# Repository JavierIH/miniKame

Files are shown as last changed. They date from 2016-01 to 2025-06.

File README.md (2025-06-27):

> 📌 **A newer and more advanced version of this robot is available:** [Kame32](https://github.com/javierih/kame32)

# Kame (MiniKame)

<p align="center">
 
</p>

[What components do I need for building this robot?](https://github.com/bqlabs/miniKame/wiki/BOM)

[Where can I find the assembly model?](https://github.com/bqlabs/miniKame/blob/develop/parts/freecad/miniKame.fcstd)

[How are servos connected to the NodeMCU V2 board?](https://github.com/JavierIH/miniKame/wiki/Map-between-servos-and-board-pins)

# License

Son of [Kame](https://github.com/bqlabs/kame)

<p align="center">

</p>

# Remixes
[PoorKame](https://github.com/owenlab/PoorKame) by [owenlab](https://github.com/owenlab)

[FatKame](https://github.com/Blomdoft/fatKame) by [Blomdoft](https://github.com/Blomdoft)

# Other

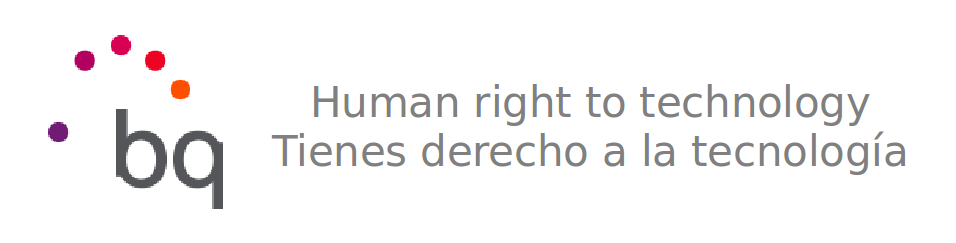
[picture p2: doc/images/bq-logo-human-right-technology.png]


Sponsored by BQ till march 2016

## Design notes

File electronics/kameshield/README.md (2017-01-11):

<p align="center">

</p>

# Attention:

This PCB is just a proof of concept of a shield for putting together the needed connectors for servos and battery on a NodeMCU V2. At this time, it has been fabricated an only one board (the one is actually being mounted on PoorKame) with a hobby-level milling machine, so I can't guarantee it to work or even if it is safe for being used with another specific hardware.

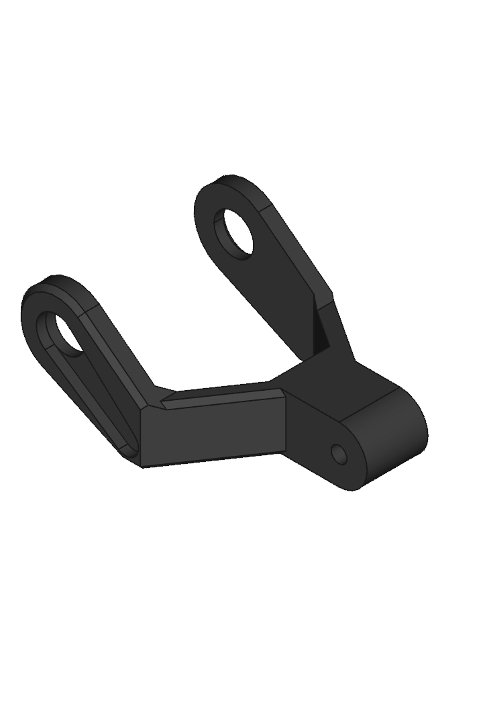
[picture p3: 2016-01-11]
doc/images/leftLegB.png

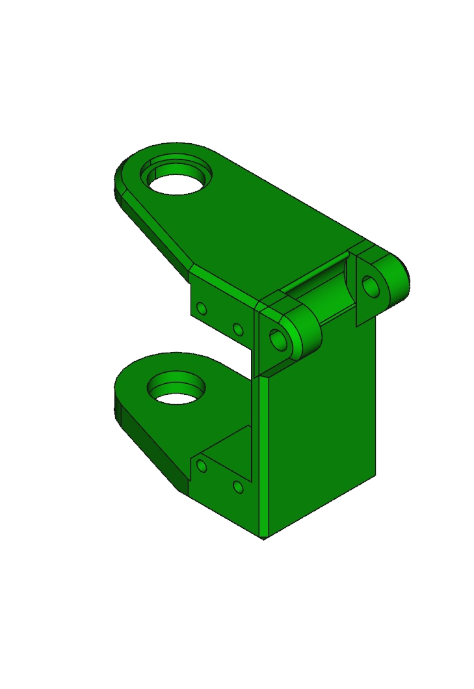
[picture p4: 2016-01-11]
doc/images/leftBracket.png

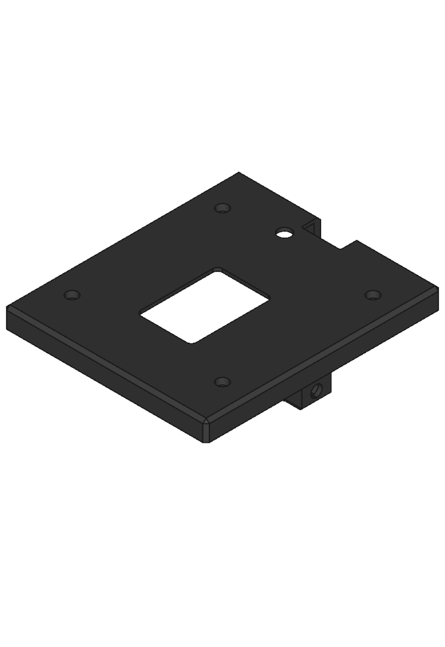
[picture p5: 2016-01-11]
doc/images/bodyA.png

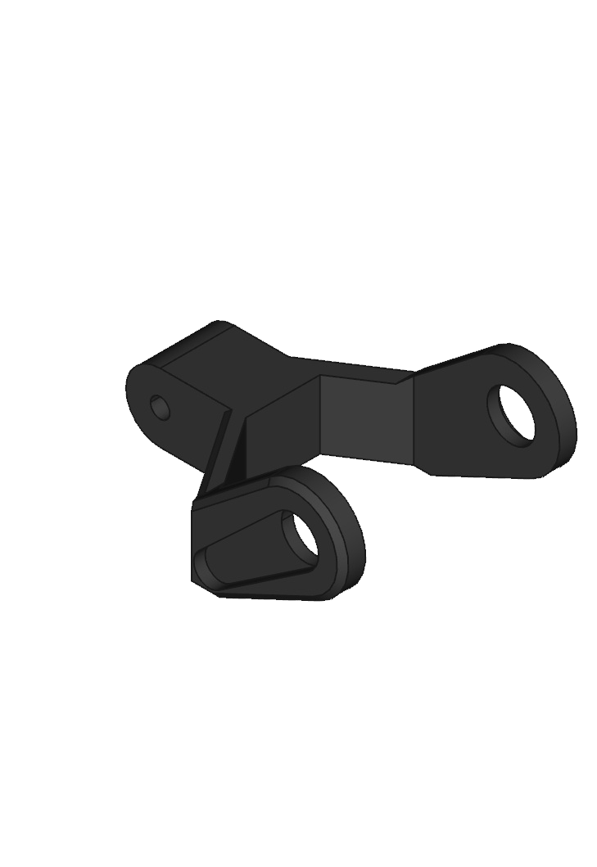
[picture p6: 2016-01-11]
doc/images/rightLegB.png

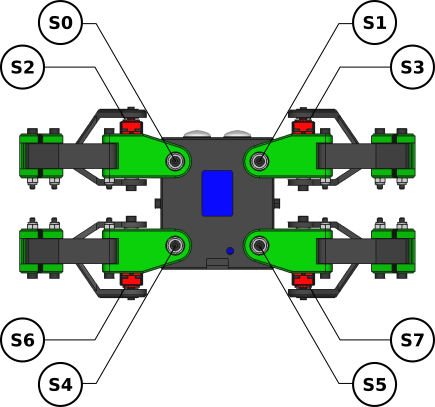
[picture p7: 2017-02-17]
doc/images/servo_scheme.png

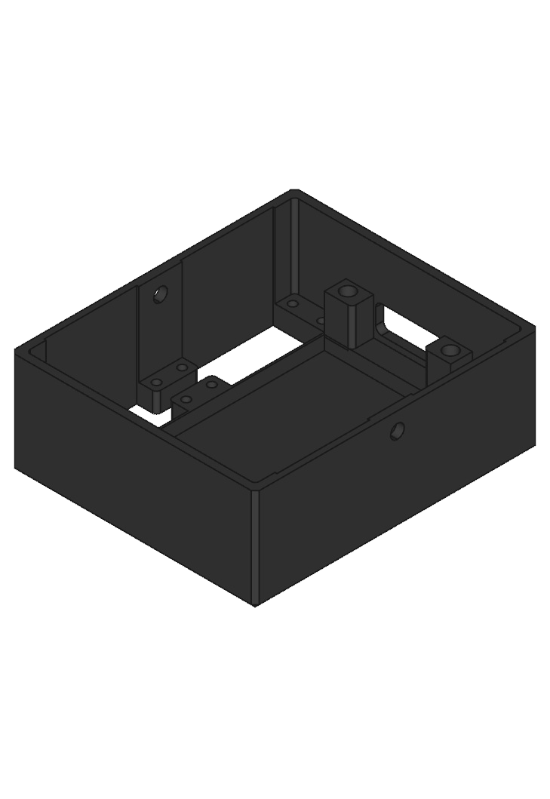
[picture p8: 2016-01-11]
doc/images/bodyB.png

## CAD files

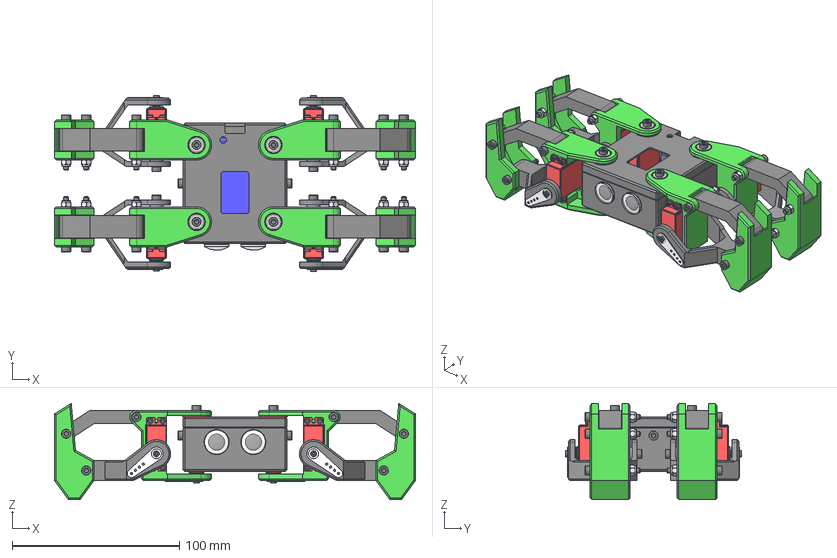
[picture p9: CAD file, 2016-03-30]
parts/freecad/miniKame.fcstd
216.0 x 105.3 x 57.6 mm
Clone of TGY-306G003
Clone of TGY-306G
Clone of TGY-306G004
Clone of TGY-306G005
Clone of TGY-306G006
Clone of TGY-306G007
Clone of TGY-306G008
Clone of TGY-306G009
Clone of horn001 (Mirror #9)
Clone of horn002 (Mirror #10)
Clone of horn001 (Mirror #11)
Clone of horn002 (Mirror #12)
Clone of legA (Mirror #17)
Clone of foot (Mirror #18)
Clone of bracket (Mirror #20)
Clone of legA (Mirror #21)
Clone of foot (Mirror #22)
Clone of bracket (Mirror #24)
Clone of legB (Mirror #30)
Clone of legB (Mirror #31)
Clone of spacer (Mirror #39)
Clone of spacer (Mirror #40)
Clone of bodyB
Clone of bodyA
eye-base
black-eye
eye-cover
eye-base001
eye-cover001
black-eye001
Clone of bearing
Clone of bearing002
Clone of bearing003
Clone of bearing004
Clone of bearing001
Clone of bearing005
Clone of bearing006
Clone of bearing007
Clone of hex-m3-8mm
Clone of hex-m3-8mm001
Clone of hex-m3-8mm002
Clone of hex-m3-8mm003
Clone of hex-m3-8mm004
Clone of hex-m3-8mm005
Clone of hex-m3-8mm006
Clone of hex-m3-8mm007
Clone of hex-m3-8mm008
Clone of hex-m3-8mm009
Clone of hex-m3-30mm
Clone of hex-m3-30mm001
Clone of hex-m3-30mm002
Clone of hex-m3-30mm003
Clone of hex-m3-30mm004
Clone of hex-m3-30mm005
Clone of hex-m3-30mm006
Clone of hex-m3-30mm007
Clone of hex-m3-30mm008
Clone of hex-m3-30mm009
Clone of hex-m3-30mm010
Clone of hex-m3-30mm011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

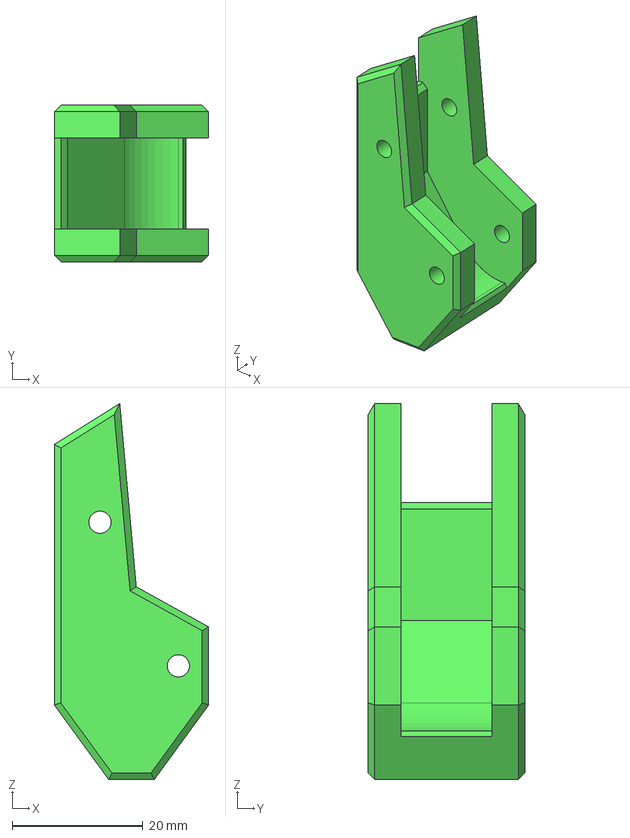
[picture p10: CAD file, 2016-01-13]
parts/step/foot.step
23.6 x 24.0 x 57.6 mm

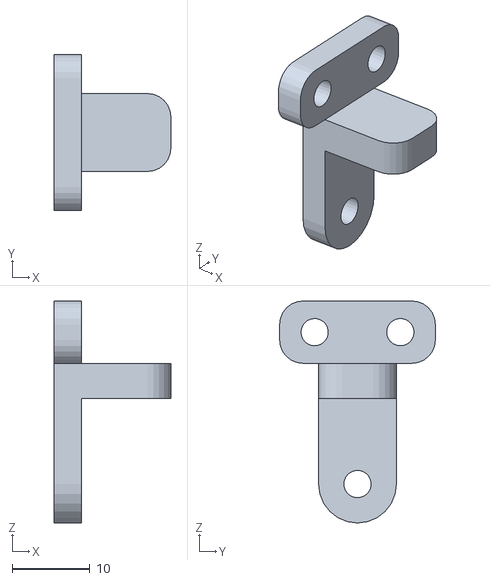
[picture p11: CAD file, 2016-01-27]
parts/stl/support.stl
15.0 x 20.0 x 28.5

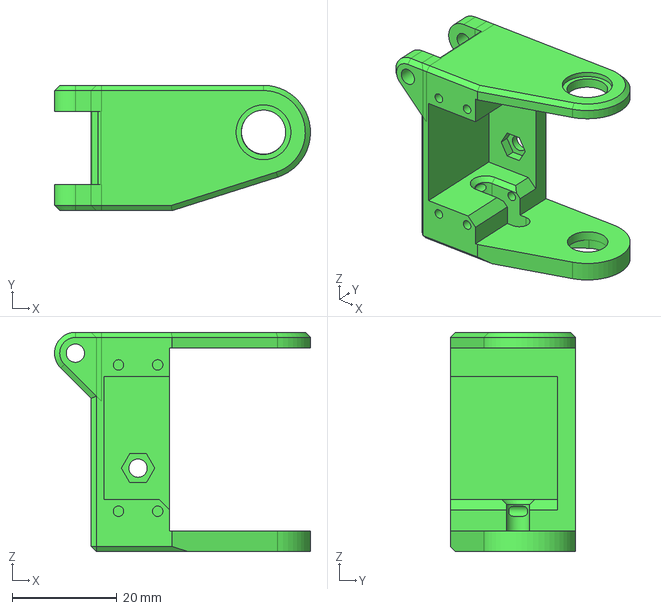
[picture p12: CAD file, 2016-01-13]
parts/step/rightBracket.step
49.0 x 24.0 x 42.0 mm

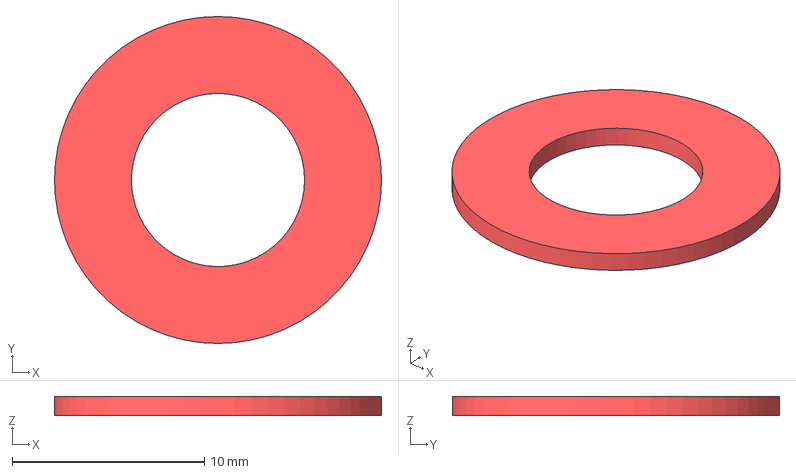
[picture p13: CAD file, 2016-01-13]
parts/step/spacer.step
17.0 x 17.0 x 1.00 mm

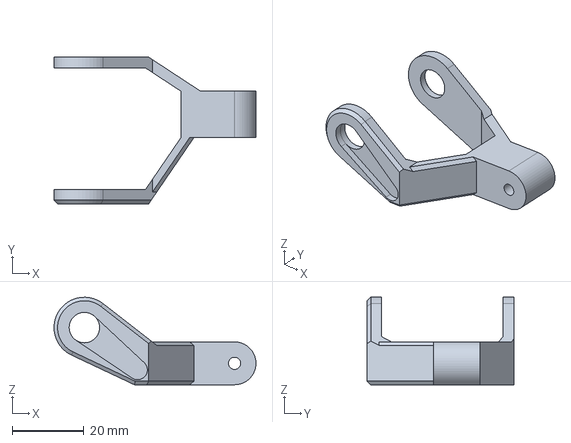
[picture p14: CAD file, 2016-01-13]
parts/step/leftLegB.step
56.5 x 41.0 x 24.5 mm

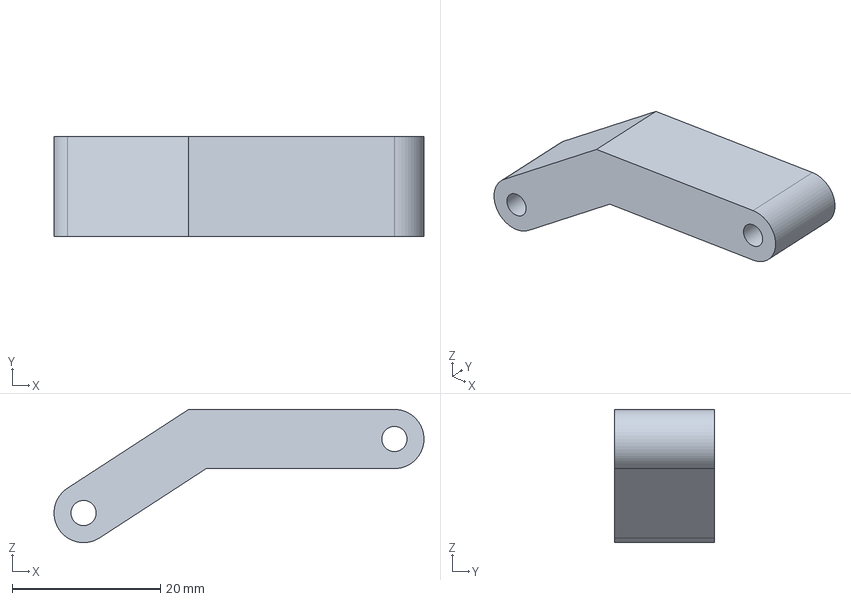
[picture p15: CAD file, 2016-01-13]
parts/step/legA.step
50.0 x 13.5 x 18.0 mm

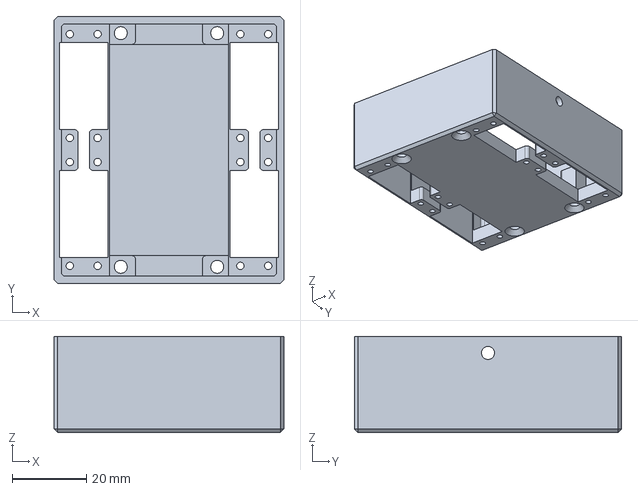
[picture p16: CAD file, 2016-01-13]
parts/step/bodyB.step
62.0 x 72.0 x 26.0 mm

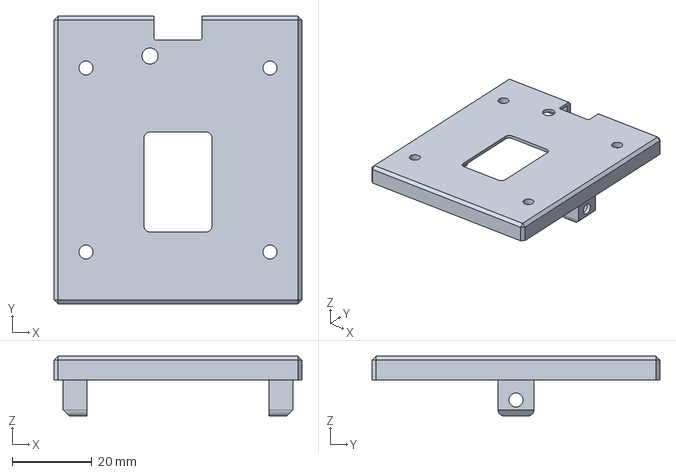
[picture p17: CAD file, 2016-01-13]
parts/step/bodyA.step
62.0 x 72.0 x 15.0 mm

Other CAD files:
parts/step/leftBracket.step
parts/step/rightLegB.step
parts/stl/bodyA.stl
parts/stl/bodyB.stl
parts/stl/foot.stl
parts/stl/leftBracket.stl
parts/stl/leftLegB.stl
parts/stl/legA.stl
parts/stl/rightBracket.stl
parts/stl/rightLegB.stl
parts/stl/spacer.stl

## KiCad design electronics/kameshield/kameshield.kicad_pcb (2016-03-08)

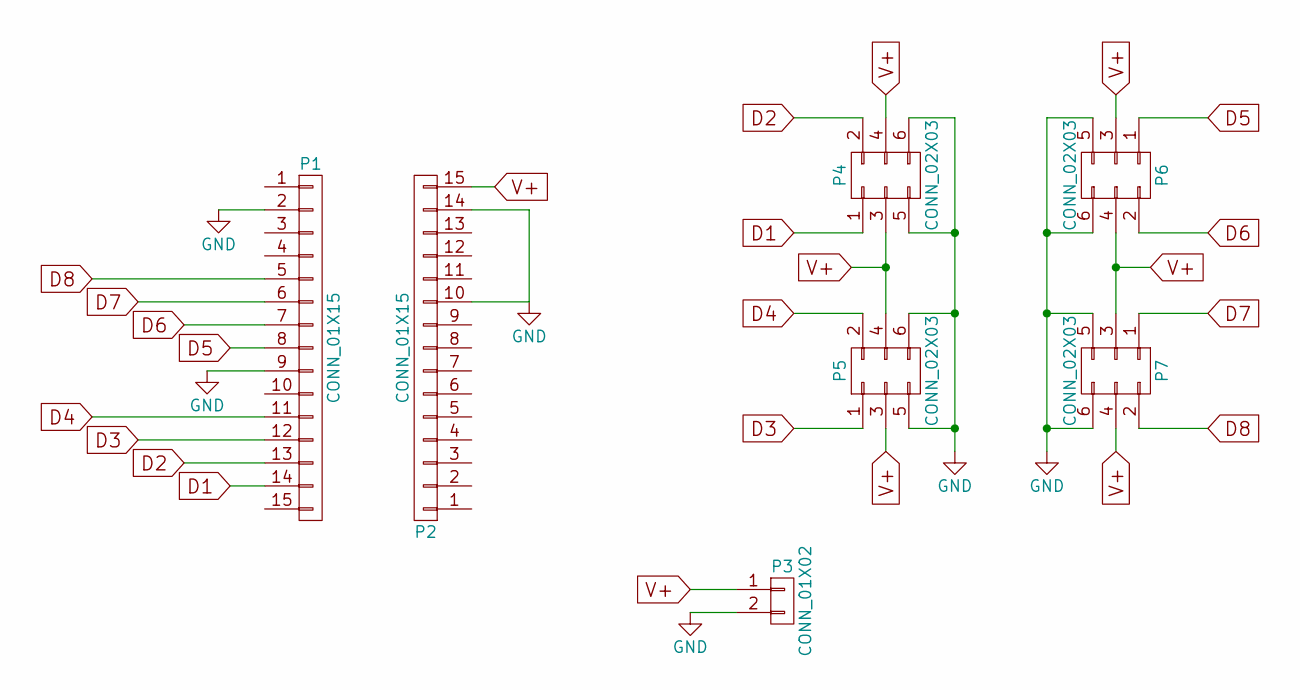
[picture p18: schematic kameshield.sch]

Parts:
P1, P2: CONN_01X15; Pin_Header_Straight_1x15
P3: CONN_01X02; Pin_Header_Straight_1x02
P4, P5, P6, P7: CONN_02X03; Pin_Header_Angled_2x03

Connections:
D1: P1.14, P4.1
D2: P1.13, P4.2
D3: P1.12, P5.1
D4: P1.11, P5.2
D5: P1.8, P6.1
D6: P1.7, P6.2
D7: P1.6, P7.1
D8: P1.5, P7.2
GND: P1.2, P1.9, P2.10, P2.14, P3.2, P4.5, P4.6, P5.5, P5.6, P6.5, P6.6, P7.5, P7.6
V+: P2.15, P3.1, P4.3, P4.4, P5.3, P5.4, P6.3, P6.4, P7.3, P7.4

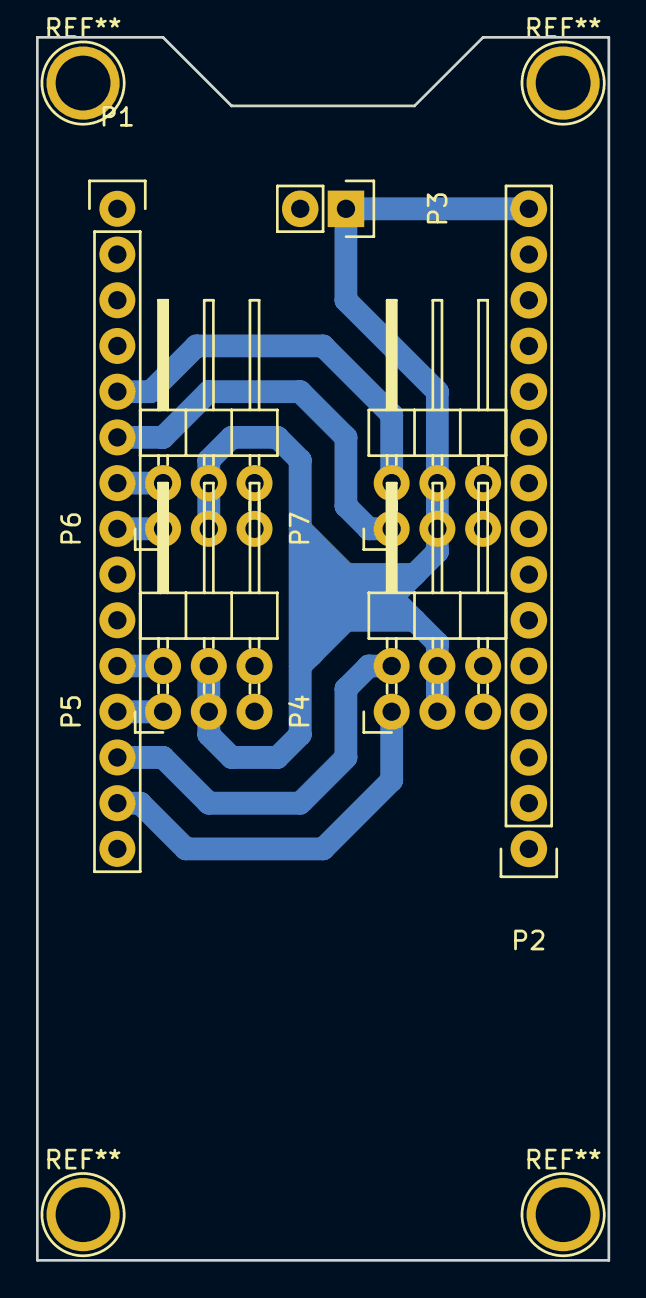
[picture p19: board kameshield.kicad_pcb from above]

Board: 2 copper layers, 31.8 x 67.9 mm, 7 parts (0 on the bottom side), 10 nets.

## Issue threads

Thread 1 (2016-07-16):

no ipaddress displayed on terminal

drepou, 2016-07-16:
Hi JavierIH

I try your sample code on my nodeMCU amica V2 i noticed that ipAddress of the board is not correctly written by  "Serial.println(WiFi.localIP());" in main.cpp

checked on arduino sample code this look to work much better :

        IPAddress myIP = WiFi.softAPIP();
        Serial.print("AP IP address: ");
	Serial.println(myIP);

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

Best Regards Yohan

JavierIH, 2016-07-18:
Hi drepou

You are right, I have just checked the code and it wasn't working properly. I'm going to update it with your code, which seems to work fine.

Thank you very much for your feedback!!!!!

drepou, 2016-07-25:
My plaisure to share and contribute...
Still Wait for my bearing to mount my kame

See you
Yohan

Envoyé de mon iPhone

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

Closed 2016-07-18.

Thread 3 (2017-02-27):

BodyB.stl file is wrong

ThorsAvenger, 2017-02-27:
The stl file for the part bodyB is wrong. Perhaps it got mixed up with another model?
https://github.com/JavierIH/miniKame/blob/develop/parts/stl/bodyB.stl

JavierIH, 2017-02-27:
Hi @ThorsAvenger , you are right this file is part of another robot, I have no idea what it is doing here...
Thank you very much for your feedback!

Closed 2017-02-27.

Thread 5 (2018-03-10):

Control it?

isoriaa, 2018-03-10:
I need some help, how to control from mobile phone, i conect to kame wifi go to 192.168.4.1 and I don`t know what to do. Is it a web, do I need a tcp socket?. Is there any android app to do it?

VTHokiEE, 2018-03-12:
I used a few tutorials that I found on-line to create a web server for the ESP8266 which hosted a page of buttons that I could press to control the robot. When the buttons are pressed they post a URL that the web server parses to obtain the command for the robot.

wheatgrinder, 2019-05-29:
you can get a telnet client for your phone.  Connect wifi to AP, connect the telnet app to the server and port.  Once connected via telnet terminal, you can send number keys to do the actions in the code.

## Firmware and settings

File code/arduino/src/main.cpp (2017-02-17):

#include <Arduino.h>
#include <ESP8266WiFi.h>
#include <WiFiClient.h>
#include <Servo.h>
#include "minikame.h"



// Wifi Access Point configuration
const char* ssid = "kame";
const char* password = "asdf";

void parseData(String data);

MiniKame robot;
WiFiServer server(80);
bool running=0;
String input;


void setup() {
    WiFi.mode(WIFI_AP);
    WiFi.softAP(ssid, password);
    server.begin();
    Serial.begin(115200);

    delay(1000);
    robot.init();
}

void loop() {
    WiFiClient client = server.available();
    if (!client) {
        IPAddress myIP = WiFi.softAPIP();
        Serial.print("AP IP address: ");
        Serial.println(myIP);
        delay(1000);
    }
    while (client.connected()) {
        if (running){
            Serial.println("running");
            if (client.available()) {
                while(client.available()) input = client.readStringUntil('+');
                parseData(input);
            }
            else {
                Serial.println("Keep Moving");
                parseData(input);
            }
        }
        else{
            Serial.println("Normal mode");
            if (client.available()) {
                while(client.available()) input = client.readStringUntil('+');
                parseData(input);
            }
            else robot.home();
        }
    }
}

void parseData(String data){

    switch (data.toInt()){

        case 1: // Up
            robot.walk(1,550);
            running = 1;
            break;

        case 2: // Down
            break;

        case 3: // Left
            robot.turnL(1,550);
            running = 1;
            break;

        case 4: // Right
            robot.turnR(1,550);
            running = 1;
            break;

        case 5: // STOP
            running = 0;
            break;

        case 6: // heart
            robot.pushUp(2,2000);
            break;

        case 7: // fire
            robot.upDown(4,250);
            break;

        case 8: // skull
            robot.jump();
            break;

        case 9: // cross
            robot.hello();
            break;

        case 10: // punch
            robot.frontBack(4,200);
            break;

        case 11: // mask
            robot.dance(2,1000);
            break;

        default:
            robot.home();
            break;
    }
}

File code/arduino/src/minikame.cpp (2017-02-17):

#include "minikame.h"


void MiniKame::init(){
    // Map between servos and board pins
    board_pins[0] = D1; // Servo S0
    board_pins[1] = D4; // Servo S1
    board_pins[2] = D8; // Servo S2
    board_pins[3] = D6; // Servo S3
    board_pins[4] = D7; // Servo S4
    board_pins[5] = D5; // Servo S5
    board_pins[6] = D2; // Servo S6
    board_pins[7] = D3; // Servo S7

    // Trim values for zero position calibration.
    trim[0] = 0;
    trim[1] = -8;
    trim[2] = 8;
    trim[3] = 5;
    trim[4] = 2;
    trim[5] = -6;
    trim[6] = 6;
    trim[7] = 5;

    // Set reverse movement
    for (int i=0; i<8; i++) reverse[i] = false;

    // Init an oscillator for each servo
    for(int i=0; i<8; i++){
        oscillator[i].start();
        servo[i].attach(board_pins[i]);
    }
    zero();
}

void MiniKame::turnR(float steps, int T=600){
    int x_amp = 15;
    int z_amp = 15;
    int ap = 15;
    int hi = 23;
    int period[] = {T, T, T, T, T, T, T, T};
    int amplitude[] = {x_amp,x_amp,z_amp,z_amp,x_amp,x_amp,z_amp,z_amp};
    int offset[] = {90+ap,90-ap,90-hi,90+hi,90-ap,90+ap,90+hi,90-hi};
    int phase[] = {0,180,90,90,180,0,90,90};

    execute(steps, period, amplitude, offset, phase);
}

void MiniKame::turnL(float steps, int T=600){
    int x_amp = 15;
    int z_amp = 15;
    int ap = 15;
    int hi = 23;
    int period[] = {T, T, T, T, T, T, T, T};
    int amplitude[] = {x_amp,x_amp,z_amp,z_amp,x_amp,x_amp,z_amp,z_amp};
    int offset[] = {90+ap,90-ap,90-hi,90+hi,90-ap,90+ap,90+hi,90-hi};
    int phase[] = {180,0,90,90,0,180,90,90};

    execute(steps, period, amplitude, offset, phase);
}

void MiniKame::dance(float steps, int T=600){
    int x_amp = 0;
    int z_amp = 40;
    int ap = 30;
    int hi = 20;
    int period[] = {T, T, T, T, T, T, T, T};
    int amplitude[] = {x_amp,x_amp,z_amp,z_amp,x_amp,x_amp,z_amp,z_amp};
    int offset[] = {90+ap,90-ap,90-hi,90+hi,90-ap,90+ap,90+hi,90-hi};
    int phase[] = {0,0,0,270,0,0,90,180};

    execute(steps, period, amplitude, offset, phase);
}

void MiniKame::frontBack(float steps, int T=600){
    int x_amp = 30;
    int z_amp = 25;
    int ap = 20;
    int hi = 30;
    int period[] = {T, T, T, T, T, T, T, T};
    int amplitude[] = {x_amp,x_amp,z_amp,z_amp,x_amp,x_amp,z_amp,z_amp};
    int offset[] = {90+ap,90-ap,90-hi,90+hi,90-ap,90+ap,90+hi,90-hi};
    int phase[] = {0,180,270,90,0,180,90,270};

    execute(steps, period, amplitude, offset, phase);
}

void MiniKame::run(float steps, int T=5000){
    int x_amp = 15;
    int z_amp = 15;
    int ap = 15;
    int hi = 15;
    int front_x = 6;
    int period[] = {T, T, T, T, T, T, T, T};
    int amplitude[] = {x_amp,x_amp,z_amp,z_amp,x_amp,x_amp,z_amp,z_amp};
    int offset[] = {    90+ap-front_x,
                        90-ap+front_x,
                        90-hi,
                        90+hi,
                        90-ap-front_x,
                        90+ap+front_x,
                        90+hi,
                        90-hi
                    };
    int phase[] = {0,0,90,90,180,180,90,90};

    execute(steps, period, amplitude, offset, phase);
}

void MiniKame::omniWalk(float steps, int T, bool side, float turn_factor){
    int x_amp = 15;
    int z_amp = 15;
    int ap = 15;
    int hi = 23;
    int front_x = 6 * (1-pow(turn_factor, 2));
    int period[] = {T, T, T, T, T, T, T, T};
    int amplitude[] = {x_amp,x_amp,z_amp,z_amp,x_amp,x_amp,z_amp,z_amp};
    int offset[] = {    90+ap-front_x,
                        90-ap+front_x,
                        90-hi,
                        90+hi,
                        90-ap-front_x,
                        90+ap+front_x,
                        90+hi,
                        90-hi
                    };

    int phase[8];
    if (side){
        int phase1[] =  {0,   0,   90,  90,  180, 180, 90,  90};
        int phase2R[] = {0,   180, 90,  90,  180, 0,   90,  90};
        for (int i=0; i<8; i++)
            phase[i] = phase1[i]*(1-turn_factor) + phase2R[i]*turn_factor;
    }
    else{
        int phase1[] =  {0,   0,   90,  90,  180, 180, 90,  90};
        int phase2L[] = {180, 0,   90,  90,  0,   180, 90,  90};
        for (int i=0; i<8; i++)
            phase[i] = phase1[i]*(1-turn_factor) + phase2L[i]*turn_factor + oscillator[i].getPhaseProgress();
    }

    execute(steps, period, amplitude, offset, phase);
}

void MiniKame::moonwalkL(float steps, int T=5000){
    int z_amp = 45;
    int period[] = {T, T, T, T, T, T, T, T};
    int amplitude[] = {0,0,z_amp,z_amp,0,0,z_amp,z_amp};
    int offset[] = {90, 90, 90, 90, 90, 90, 90, 90};
    int phase[] = {0,0,0,120,0,0,180,290};

    execute(steps, period, amplitude, offset, phase);
}

void MiniKame::walk(float steps, int T=5000){
    int x_amp = 15;
    int z_amp = 20;
    int ap = 20;
    int hi = 10;
    int front_x = 12;
    int period[] = {T, T, T/2, T/2, T, T, T/2, T/2};
    int amplitude[] = {x_amp,x_amp,z_amp,z_amp,x_amp,x_amp,z_amp,z_amp};
    int offset[] = {   90+ap-front_x,
                                90-ap+front_x,
                                90-hi,
                                90+hi,
                                90-ap-front_x,
                                90+ap+front_x,
                                90+hi,
                                90-hi
                    };
    int  phase[] = {90, 90, 270, 90, 270, 270, 90, 270};

    for (int i=0; i<8; i++){
        oscillator[i].reset();
        oscillator[i].setPeriod(period[i]);
        oscillator[i].setAmplitude(amplitude[i]);
        oscillator[i].setPhase(phase[i]);
        oscillator[i].setOffset(offset[i]);
    }

    _final_time = millis() + period[0]*steps;
    _init_time = millis();
    bool side;
    while (millis() < _final_time){
        side = (int)((millis()-_init_time) / (period[0]/2)) % 2;
        setServo(0, oscillator[0].refresh());
        setServo(1, oscillator[1].refresh());
        setServo(4, oscillator[4].refresh());
        setServo(5, oscillator[5].refresh());

        if (side == 0){
            setServo(3, oscillator[3].refresh());
            setServo(6, oscillator[6].refresh());
        }
        else{
            setServo(2, oscillator[2].refresh());
            setServo(7, oscillator[7].refresh());
        }
        delay(1);
    }
}

void MiniKame::upDown(float steps, int T=5000){
    int x_amp = 0;
    int z_amp = 35;
    int ap = 20;
    int hi = 25;
    int front_x = 0;
    int period[] = {T, T, T, T, T, T, T, T};
    int amplitude[] = {x_amp,x_amp,z_amp,z_amp,x_amp,x_amp,z_amp,z_amp};
    int offset[] = {    90+ap-front_x,
                        90-ap+front_x,
                        90-hi,
                        90+hi,
                        90-ap-front_x,
                        90+ap+front_x,
                        90+hi,
                        90-hi
                    };
    int phase[] = {0,0,90,270,180,180,270,90};

    execute(steps, period, amplitude, offset, phase);
}
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

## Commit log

2015-11-26 Add freecad project
    [miniKame.fcstd]
2015-11-26 Add stl files
    [bodyA.stl, bodyB.stl, bracket.stl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]
2015-11-30 updated body for nodemcu
    [bodyA.stl, bodyB.stl, miniKame.fcstd]
2015-12-01 reinforced bearing cavitiy on legB
    [legB.stl, miniKame.fcstd]
2015-12-01 Added bearings on 3d model
    [miniKame.fcstd]
2015-12-14 updated 3d model
    [bodyA.stl, bodyB.stl, miniKame.fcstd]
2015-12-15 added spacers for the body-bracket joint
    [miniKame.fcstd, spacer.stl]
2015-12-22 Added new functions and solved reset bug
    [main.cpp, minikame.cpp]
2016-01-11 Added bolts and nuts on freecad project
    [miniKame.fcstd]
2016-01-11 Added bolts for yaw servos
    [miniKame.fcstd]
2016-01-11 Generated stl files for leg parts
    [leftBracket.stl, leftLegB.stl, rightBracket.stl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]
2016-01-11 Deleted duplicated files
    [bracket.stl, legB.stl]
2016-01-13 generated step parts
    [bodyA.step, bodyB.step, foot.step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]
2016-01-25 Added an experimental shield (not working yey
    [kameshield.kicad_pcb, kameshield.sch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]
2016-01-27 body support
    [miniKame.fcstd]
2016-01-27 generated stl
    [miniKame.fcstd, support.stl]
2016-01-27 modded support
    [miniKame.fcstd, support.stl]
2016-03-08 shield for kame
    [kameshield.kicad_pcb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]
2016-03-30 last commit
    [miniKame.fcstd]
2016-06-14 updates octosnake and solves calibration bug
    [main.cpp, minikame.cpp]
2016-06-16 omniwalk calibration
2016-07-18 Fix IP print at the start
    [main.cpp]
2017-01-11 regenerated gerbers and added a solder mask
    [kameshield-B.Cu.gbr, kameshield-B.Mask.gbr, kameshield-Edge.Cuts.gbr]
2017-02-17 fixed warnings, added comments
    [main.cpp, minikame.cpp]
2017-02-27 uploading the correct body part. fix #3
    [bodyB.stl]
